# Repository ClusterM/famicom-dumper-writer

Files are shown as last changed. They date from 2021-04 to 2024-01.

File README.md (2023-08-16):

# Famicom/NES Dumper/Writer

## Overview

This is a powerfull dumper/writer for Famicom/NES cartridges and Famicom Disc System cards. The goal of the project is to create an ideal famicom data bus simulator. It's using a very accurate M2 cycle simulation and FSMC (Flexible Static Memory Controller) to access PRG and CHR memory. FSMC is precisely synchronized with the M2 clock signal using a CPLD chip. Also, this device is very fast.





COOLBOY writing using GPIO pins

Video about dumper development (English subtitles):

Video preview (https://youtu.be/j_rteVX5q-g)

You can use it to:

* Dump cartridges, so you can play copy of your cartridge on emulator.
* Dump reset-based cartridges, there is command to simulate reset press.
* Dump cartridges that requires a continuous clock on M2 pin.
* Use it with [very flexible and multiplatform client](https://github.com/ClusterM/famicom-dumper-client), it's using C# scripts.
* Read/write battery backed saves, so that you can continue your saved game on emulator/console and vice-versa.
* (Re)write [COOLGIRL](https://github.com/ClusterM/coolgirl-famicom-multicard) cartridges.
* (Re)write ultracheap chinese [COOLBOY (AA6023 chip based)](https://www.nesdev.org/wiki/NES_2.0_Mapper_268) cartridges (mapper 268). Soldering is required for a cheap cartridges but it's very simple. Some more expensive cartridges can be rewritten without soldering.
* (Re)write UNROM-512 cartridges (RetroUSB, mapper 30).
* Read and write Famicom Disk System cards using FDS drive with the RAM adapter.
* Test your cartridges.
* Do some reverse engineering.
* Anything else that requires Famicom/NES bus simulation.

## Schematic

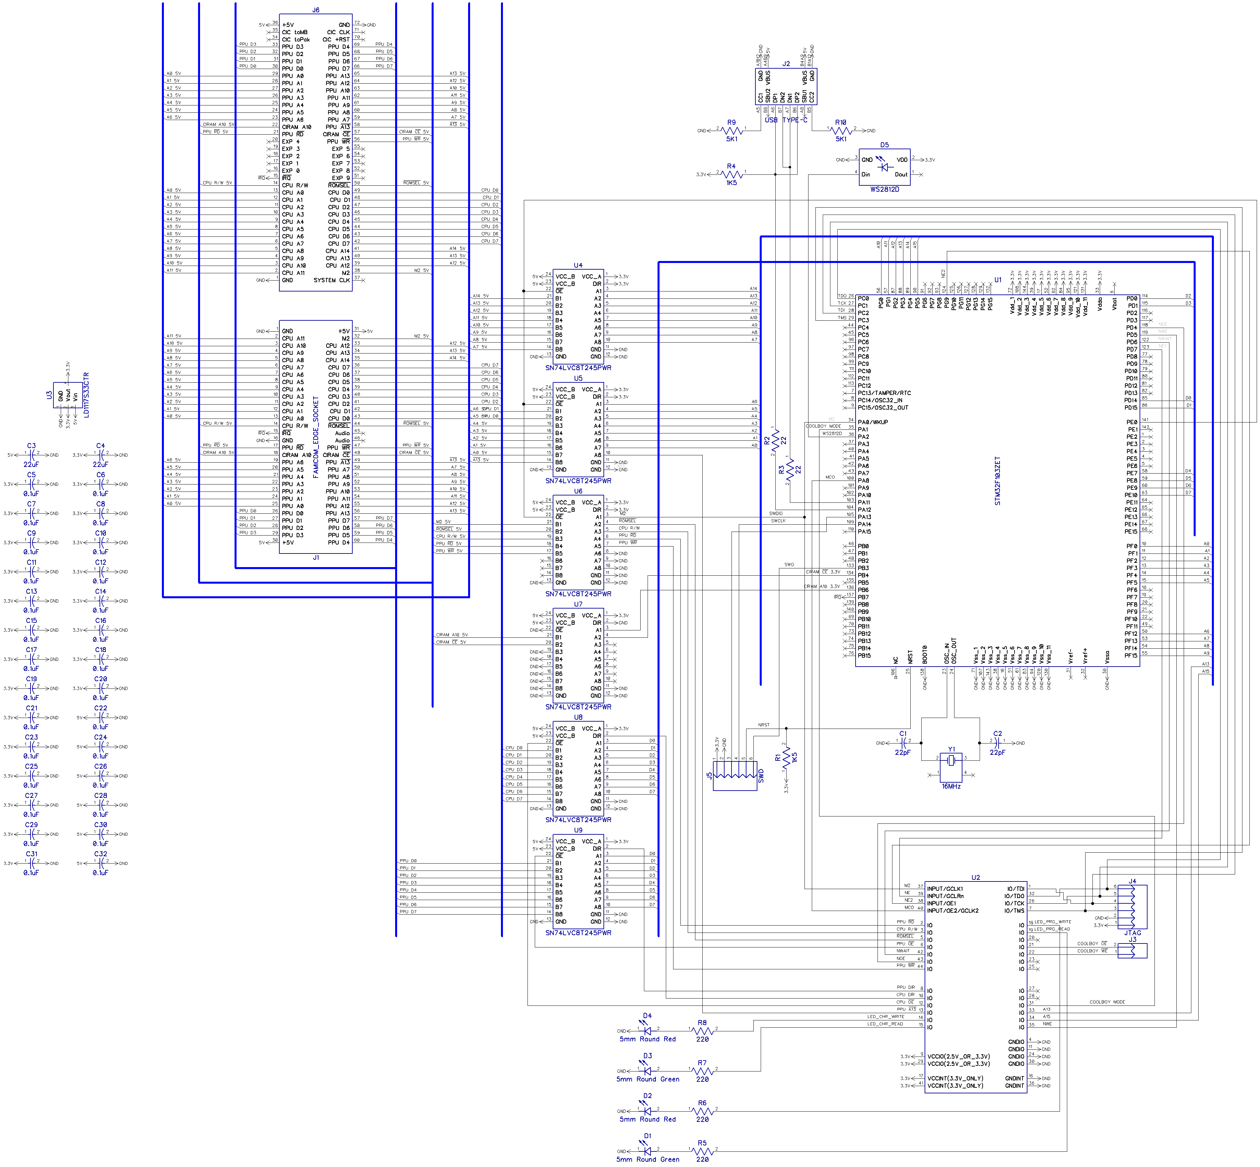
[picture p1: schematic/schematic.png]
Schematic


Bill of Materials:

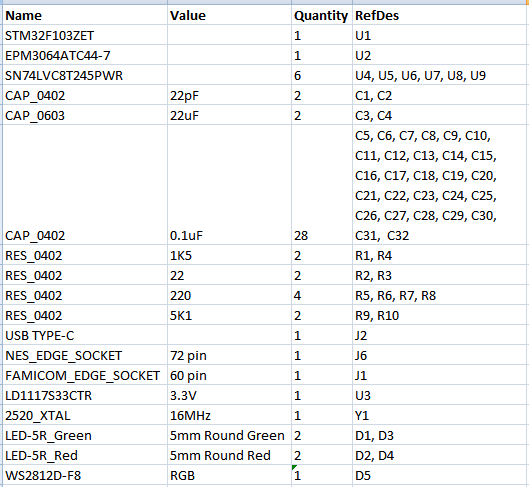
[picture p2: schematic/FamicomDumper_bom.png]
BoM


## Firmware

You need to write firmware to two chips: the STM32F103ZET microcontroller and the EPM3064 CPLD. But actually you need only to flash bootloader to STM32 using ST-Link programmer. Using bootloader you can flash both firmwares: to the STM32F103ZET and to the EPM3064.

How to use bootloader:
* Disconnect device from USB.
* Short the ground and the IRQ pins using tweezers or scissors.

* Connect the device to the USB of your PC/Mac. The RGB LED should turn green. Try again if it's not green.
* Remove tweezers/scissors quickly while the LED is green.
* The LED should turn yellow. Try again if it's not yellow.
* The device should be detected as USB drive.
* Format it to FAT32 if it's not formatted yet. You need to do it only once.
* Write SVF file with the firmware for the EPM3064 chip and BIN file with the firmware for the STM32F103ZET chip to this USB drive. You can write both at the same time.
* The RGB LED should turn white.
* Wait for some time: ~30 seconds for EPM3064 firmware, ~1 second for STM32F103ZET firmware.
* The RGB LED should turn green on success, red on some error.
* Reconnect device to your PC/Mac.

You can update the firmwares using the same way without any additional hardware (only tweezers or scissors :))

## Driver

This device shound work without any additional drivers on all modern operating systems, as virtual serial port.

## Software

[https://github.com/ClusterM/famicom-dumper-client](https://github.com/ClusterM/famicom-dumper-client)

## Donate
PayPal: cluster@cluster.wtf

https://www.donationalerts.com/r/clustermeerkat

https://boosty.to/cluster

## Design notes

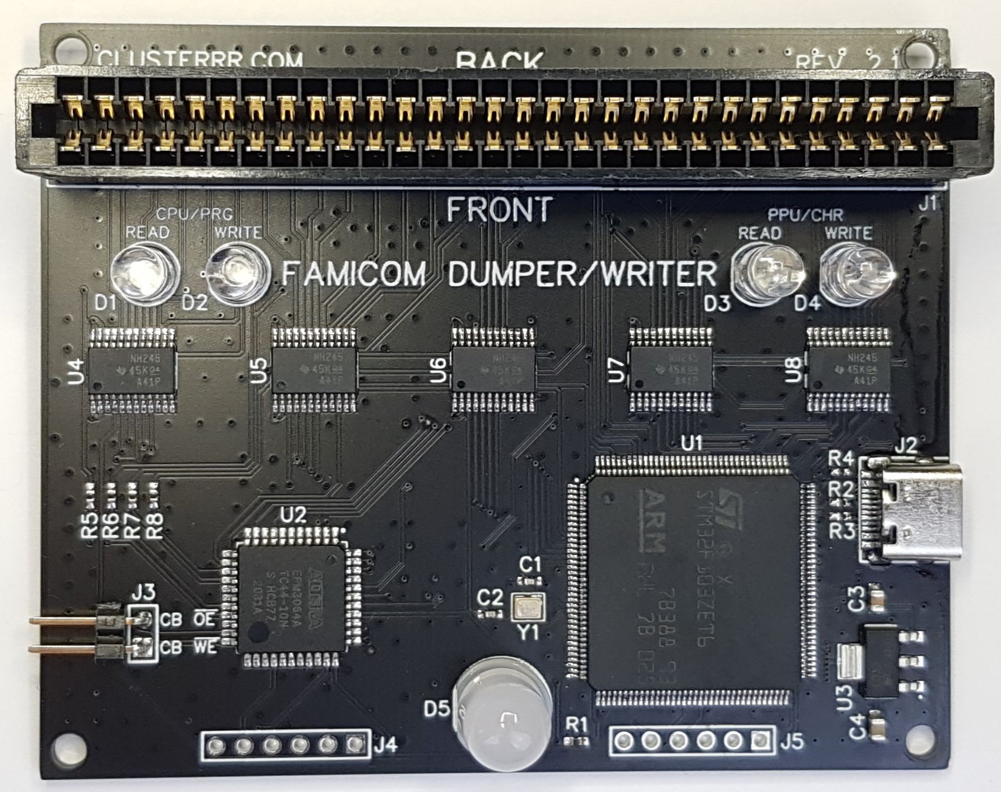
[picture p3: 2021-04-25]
photos/dumper2.jpg

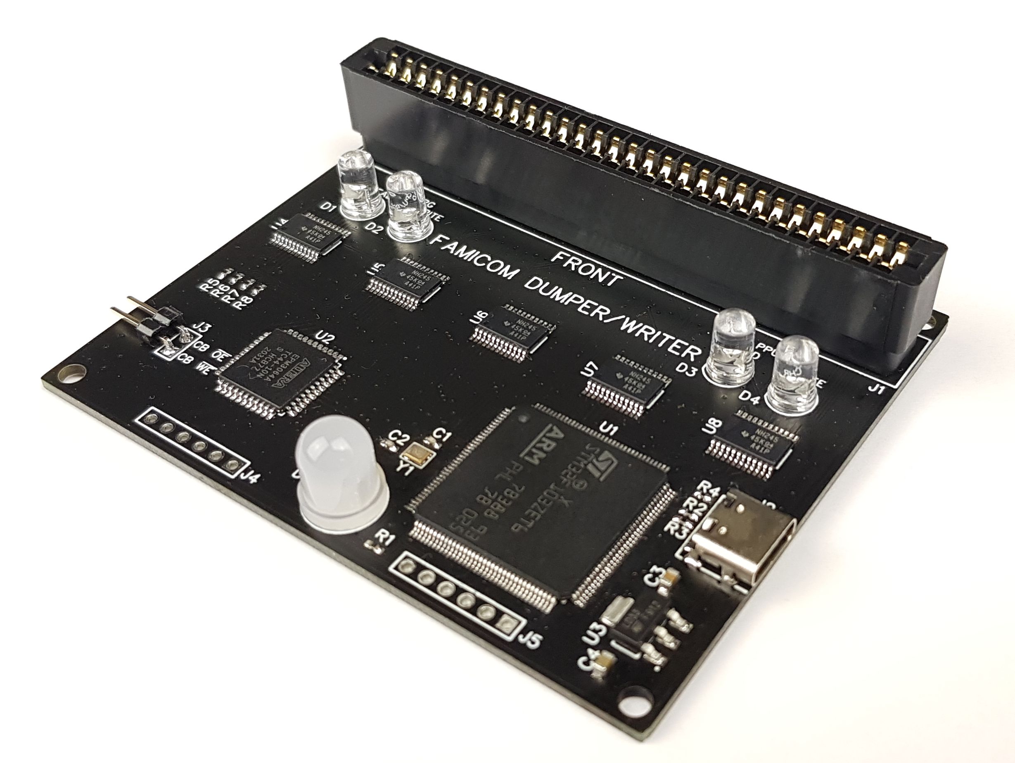
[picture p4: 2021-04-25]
photos/dumper.jpg

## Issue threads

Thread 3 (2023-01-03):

Alternative CPLD?

djbiohazard, 2023-01-03:
The EPM3064 seems to be EOL, is there any other alternative chip that could be used?

ClusterM, 2023-01-19:
Yes, i think. But it's developed for EPM3064 and there is no pin-compatible alternatives :( Need to change schematic and board for  something else.

ClusterM, 2023-01-20:
I think that it's possible to migrate to EPM7064AETC44.

derchr, 2023-10-20:
Hello, is it possible to use EPM3064ATC44-10N instead of EPM3064ATC44-7 as the latter one is hardly available?

ClusterM, 2023-10-22:
> Hello, is it possible to use EPM3064ATC44-10N instead of EPM3064ATC44-7 as the latter one is hardly available?

Hi! Yes, they are compatible as far as i can remember.

derchr, 2023-10-24:
> > Hello, is it possible to use EPM3064ATC44-10N instead of EPM3064ATC44-7 as the latter one is hardly available?
>
> Hi! Yes, they are compatible as far as i can remember.

Thanks!

Closed 2023-08-07.

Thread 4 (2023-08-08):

Configuration of Altera EPM3064 cant' be updated

kolmogorovpavel, 2023-08-08:
After copying file FamicomDumper.svf to drive, led is always become red. After reconnecting drive the file is still there.

Regle-Lin, 2023-08-11:
when I programmed the FamicomDumperBootloader.bin or FamicomDumper.bin to STM32 MCU by STLINK V2 and connect the dumper to USB, the device cannot recognize by PC(win10 64 bit), the PC showing unknow device, if anyone could give a guidance for how to make it work will be appreciated.

kolmogorovpavel, 2023-08-11:
You just need to programm FamicomDumperBootloader.bin to STM32 MCU by STLINK V2. (Power dumper by usb) Then you should short 15 and 16 pin and connect to usb, then remove connection between 15 an 16 (you can see it in the video). The led become green first, then yellow and USB drive will be detected. You should format it before copying FamicomDumper.bin to the drive.

Regle-Lin, 2023-08-12:
My dumper now working perfect! my problem is I'm used the oscillator(need provide vdd for work) not the crystal for STM32, so I need to re-soldering the right pin for let the 16M signal input from STM32 pin23.
in your case, maybe you need to check the ALTERA chip soldering if any shorted pin or mounted in wrong direction(such mistaken happened to me), if confirmed no any hardware issues, please try to update the FW one by one, try only the STM32 BIN first and then CPLD, when the CPLD FW updating, all the read/write LED is dim light and the CHR red LED will be solid light when the CPLD FW update done.

kolmogorovpavel, 2023-08-13:
In my case dumper was bought maybe a year or two ago. So it has an old firmware. A updated bootloader first with stlink, then stm32 firmware by copying to 192kb drive. Dumper is working now, but I can't update CPLD. Maybe old pcb has some differences. But all tryes to copy svf ended up with red light of rgb led.

Regle-Lin, 2023-08-14:
you can try to use the USB-BLASTER for the CPLD programming, but I'm suggest you to check the connection differences to the latest release of PCB layout.

serperus, 2023-10-12:
> In my case dumper was bought maybe a year or two ago. So it has an old firmware. A updated bootloader first with stlink, then stm32 firmware by copying to 192kb drive. Dumper is working now, but I can't update CPLD. Maybe old pcb has some differences. But all tryes to copy svf ended up with red light of rgb led.

Try to copy to sd card both files together. Bin and svf at the same time.

kolmogorovpavel, 2023-10-15:
> Try to copy to ubs flash both files together. Bin and svf at the same time.
That was the first that I've tried. With no luck.

ClusterM, 2024-02-13:
> In my case dumper was bought maybe a year or two ago. So it has an old firmware. A updated bootloader first with stlink, then stm32 firmware by copying to 192kb drive. Dumper is working now, but I can't update CPLD. Maybe old pcb has some differences. But all tryes to copy svf ended up with red light of rgb led.

Hi. Which dumper revision you have? Only rev3.2+ has CPLD programming lines. So you can't update CPLD firmware via bootloader on old PCBs even with the latest bootloader.

kolmogorovpavel, 2024-02-14:
Revision of my PCB is 2.1.
So it is clear now that I should use usb-blaster.

Closed 2024-03-18.

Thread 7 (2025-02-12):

PC can not recogonize the stm32

hualazimo7, 2025-02-12:
when I programmed the FamicomDumperBootloader.bin or FamicomDumper.bin to STM32 MCU by STLINK V2 and connect the dumper to USB, the device cannot be recognized by PC(win10 64 bit), the PC showing unknow device, if anyone could give a guidance for how to make it work will be appreciated.

BTW I used the right 16MHZ crystal.

hualazimo7, 2025-02-12:
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

I didn't change the layout jusy replace some 0402 components by 0603 ones.

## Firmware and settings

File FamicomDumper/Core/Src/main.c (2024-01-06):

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
/* Includes ------------------------------------------------------------------*/
#include "main.h"
#include "usb_device.h"

/* USER CODE BEGIN Includes */
#include <stdio.h>
#include "dumper.h"
#include "comm.h"
#include "flash.h"
#include "unrom512.h"
#include "fds.h"
#include "led.h"
/* USER CODE END Includes */

TIM_HandleTypeDef htim1;
TIM_HandleTypeDef htim2;
TIM_HandleTypeDef htim3;
TIM_HandleTypeDef htim4;
TIM_HandleTypeDef htim5;
DMA_HandleTypeDef hdma_tim5_ch3_up;

SRAM_HandleTypeDef hsram1;
SRAM_HandleTypeDef hsram2;

void SystemClock_Config(void);
static void MX_GPIO_Init(void);
static void MX_DMA_Init(void);
static void MX_FSMC_Init(void);
static void MX_TIM2_Init(void);
static void MX_TIM5_Init(void);
static void MX_TIM1_Init(void);
static void MX_TIM3_Init(void);
static void MX_TIM4_Init(void);
/* USER CODE BEGIN 0 */
int _write(int file, char *ptr, int len)
{
  for (int i = 0; i < len; i++)
    ITM_SendChar((*ptr++));
  return len;
}

/* USER CODE END 0 */

/**
  * @brief  The application entry point.
  * @retval int
  */
int main(void)
{
  /* MCU Configuration--------------------------------------------------------*/

  /* Reset of all peripherals, Initializes the Flash interface and the Systick. */
  HAL_Init();

  /* Configure the system clock */
  SystemClock_Config();

  /* Initialize all configured peripherals */
  MX_GPIO_Init();
  MX_DMA_Init();
  MX_FSMC_Init();
  MX_USB_DEVICE_Init();
  MX_TIM2_Init();
  MX_TIM5_Init();
  MX_TIM1_Init();
  MX_TIM3_Init();
  MX_TIM4_Init();
  /* USER CODE BEGIN 2 */
  // Microsecond counter
  HAL_TIM_Base_Start(&htim1);
  // M2 PWM
  HAL_TIM_PWM_Start(&htim2, TIM_CHANNEL_1);
  // 1000*M2 clock counter (slave of htim2 with /1000 prescaler)
  HAL_TIM_Base_Start(&htim3);
  // M2 clock counter (slave of htim2)
  HAL_TIM_Base_Start(&htim4);
  comm_init();
  printf("Started.\n");
  /* USER CODE END 2 */

  /* Infinite loop */
  /* USER CODE BEGIN WHILE */
  uint16_t address;
  uint32_t address32;
  uint16_t length;
  led_blue();

  while (1)
  {
    led_idle();

    if (comm_recv_done)
    {
      comm_recv_done = 0;
      switch (comm_recv_command)
      {
      case COMMAND_PRG_INIT:
        comm_start(COMMAND_PRG_STARTED, 13);
        comm_send_byte(PROTOCOL_VERSION);
        comm_send_byte(0xFF);
        comm_send_byte(0xFF); // unlimited send buffer
        comm_send_byte((RECV_BUFFER_SIZE - 8) & 0xFF);
        comm_send_byte(((RECV_BUFFER_SIZE - 8) >> 8) & 0xFF);
        comm_send_byte(FIRMWARE_VERSION_MAJOR & 0xFF);
        comm_send_byte((FIRMWARE_VERSION_MAJOR >> 8) & 0xFF);
        comm_send_byte(FIRMWARE_VERSION_MINOR);
        comm_send_byte(FIRMWARE_VERSION_SUFFIX);
#ifndef DEBUG
        comm_send_byte(HARDWARE_VERSION[0]);
        comm_send_byte(HARDWARE_VERSION[1]);
        comm_send_byte(HARDWARE_VERSION[2]);
        comm_send_byte(HARDWARE_VERSION[3]);
#else
        comm_send_byte(0);
        comm_send_byte(0);
        comm_send_byte(0);
        comm_send_byte(0);
#endif
        set_coolboy_gpio_mode(0);
        break;

      case COMMAND_COOLBOY_READ_REQUEST:
      case COMMAND_PRG_READ_REQUEST:
        address = recv_buffer[0] | ((uint16_t) recv_buffer[1] << 8);
        length = recv_buffer[2] | ((uint16_t) recv_buffer[3] << 8);
        read_prg_send(address, length);
        break;

      case COMMAND_PRG_CRC_READ_REQUEST:
        address = recv_buffer[0] | ((uint16_t) recv_buffer[1] << 8);
        length = recv_buffer[2] | ((uint16_t) recv_buffer[3] << 8);
        read_prg_crc_send(address, length);
        break;

      case COMMAND_PRG_WRITE_REQUEST:
        address = recv_buffer[0] | ((uint16_t) recv_buffer[1] << 8);
        length = recv_buffer[2] | ((uint16_t) recv_buffer[3] << 8);
        write_prg(address, length, (uint8_t*) &recv_buffer[4]);
        comm_start(COMMAND_PRG_WRITE_DONE, 0);
        break;

      case COMMAND_RESET:
        reset();
        comm_start(COMMAND_RESET_ACK, 0);
        break;

      case COMMAND_FLASH_ERASE_SECTOR_REQUEST:
      case COMMAND_COOLBOY_ERASE_SECTOR_REQUEST:
        erase_flash_sector();
        break;

      case COMMAND_FLASH_WRITE_REQUEST:
      case COMMAND_COOLBOY_WRITE_REQUEST:
        address = recv_buffer[0] | ((uint16_t) recv_buffer[1] << 8);
        length = recv_buffer[2] | ((uint16_t) recv_buffer[3] << 8);
        write_flash(address, length, (uint8_t*) &recv_buffer[4]);
        break;

      case COMMAND_UNROM512_ERASE_REQUEST:
        erase_unrom512();
        break;

      case COMMAND_UNROM512_WRITE_REQUEST:
        address32 = recv_buffer[0] | ((uint32_t) recv_buffer[1] << 8) | ((uint32_t) recv_buffer[2] << 16) | ((uint32_t) recv_buffer[3] << 24);
        length = recv_buffer[4] | ((uint16_t) recv_buffer[5] << 8);
        write_unrom512(address32, length, (uint8_t*) &recv_buffer[6]);
        break;

      case COMMAND_CHR_INIT:
        comm_start(COMMAND_CHR_STARTED, 0);
        break;

      case COMMAND_CHR_READ_REQUEST:
        address = recv_buffer[0] | ((uint16_t) recv_buffer[1] << 8);
        length = recv_buffer[2] | ((uint16_t) recv_buffer[3] << 8);
        read_chr_send(address, length);
        break;

      case COMMAND_CHR_CRC_READ_REQUEST:
        address = recv_buffer[0] | ((uint16_t) recv_buffer[1] << 8);
        length = recv_buffer[2] | ((uint16_t) recv_buffer[3] << 8);
        read_chr_crc_send(address, length);
        break;

      case COMMAND_CHR_WRITE_REQUEST:
        address = recv_buffer[0] | ((uint16_t) recv_buffer[1] << 8);
        length = recv_buffer[2] | ((uint16_t) recv_buffer[3] << 8);
        write_chr(address, length, (uint8_t*) &recv_buffer[4]);
        comm_start(COMMAND_CHR_WRITE_DONE, 0);
        break;

      case COMMAND_FDS_READ_REQUEST:
        fds_transfer(recv_buffer[0], recv_buffer[1], 0, 0, 0, 0);
        break;

      case COMMAND_FDS_WRITE_REQUEST:
        fds_transfer(0, 0, recv_buffer[0], (uint8_t*) &recv_buffer[1], (uint16_t*) &recv_buffer[1 + recv_buffer[0]], (uint8_t*) &recv_buffer[1 + recv_buffer[0] + recv_buffer[0] * 2]);
        break;

      case COMMAND_MIRRORING_REQUEST:
        get_mirroring();
        break;

      case COMMAND_SET_FLASH_BUFFER_SIZE:
        set_flash_buffer_size(recv_buffer[0] | ((uint16_t) recv_buffer[1] << 8));
        comm_start(COMMAND_SET_VALUE_DONE, 0);
        break;

      case COMMAND_SET_COOLBOY_GPIO_MODE:
        set_coolboy_gpio_mode(recv_buffer[0]);
        comm_start(COMMAND_SET_VALUE_DONE, 0);
        break;
      }
      led_off();
    }
    /* USER CODE END WHILE */

    /* USER CODE BEGIN 3 */
  }
  /* USER CODE END 3 */
}

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


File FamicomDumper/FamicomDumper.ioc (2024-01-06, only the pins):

Mcu.UserName=STM32F103ZETx
PA0-WKUP.GPIO_Label=M2
PA0-WKUP.Signal=S_TIM2_CH1_ETR
PA1.GPIO_Label=COOLBOY_MODE
PA1.Signal=GPIO_Output
PA11.Signal=USB_DM
PA12.Signal=USB_DP
PA13.Signal=SYS_JTMS-SWDIO
PA14.Signal=SYS_JTCK-SWCLK
PA2.GPIO_Label=WS2812
PA2.Signal=S_TIM5_CH3
PA8.Signal=RCC_MCO
PB3.Signal=SYS_JTDO-TRACESWO
PB4.GPIO_Label=CIRAM_CE
PB4.Signal=GPIO_Input
PB6.GPIO_Label=CIRAM_A10
PB6.Signal=GPIO_Input
PB7.GPIO_Label=IRQ
PB7.Signal=GPIO_Input
PC0.GPIO_Label=TDO
PC0.Signal=GPIO_Input
PC1.GPIO_Label=TCK
PC1.Signal=GPIO_Input
PC2.GPIO_Label=TDI
PC2.Signal=GPIO_Input
PC3.GPIO_Label=TMS
PC3.Signal=GPIO_Input
PD0.Signal=FSMC_D2_DA2
PD1.Signal=FSMC_D3_DA3
PD14.Signal=FSMC_D0_DA0
PD15.Signal=FSMC_D1_DA1
PD4.Signal=FSMC_NOE
PD5.Signal=FSMC_NWE
PD6.Signal=FSMC_NWAIT
PD7.Signal=FSMC_NE1
PE0.GPIO_Label=SHIFTERS_OE
PE0.Signal=GPIO_Output
PE10.Signal=FSMC_D7_DA7
PE7.Signal=FSMC_D4_DA4
PE8.Signal=FSMC_D5_DA5
PE9.Signal=FSMC_D6_DA6
PF0.Signal=FSMC_A0
PF1.Signal=FSMC_A1
PF12.Signal=FSMC_A6
PF13.Signal=FSMC_A7
PF14.Signal=FSMC_A8
PF15.Signal=FSMC_A9
PF2.Signal=FSMC_A2
PF3.Signal=FSMC_A3
PF4.Signal=FSMC_A4
PF5.Signal=FSMC_A5
PG0.Signal=FSMC_A10
PG1.Signal=FSMC_A11
PG2.Signal=FSMC_A12
PG3.Signal=FSMC_A13
PG4.Signal=FSMC_A14
PG5.Signal=FSMC_A15
PG9.Signal=FSMC_NE2

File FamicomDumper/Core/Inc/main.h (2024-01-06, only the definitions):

#define TDO_Pin GPIO_PIN_0
#define TDO_GPIO_Port GPIOC
#define TCK_Pin GPIO_PIN_1
#define TCK_GPIO_Port GPIOC
#define TDI_Pin GPIO_PIN_2
#define TDI_GPIO_Port GPIOC
#define TMS_Pin GPIO_PIN_3
#define TMS_GPIO_Port GPIOC
#define M2_Pin GPIO_PIN_0
#define M2_GPIO_Port GPIOA
#define COOLBOY_MODE_Pin GPIO_PIN_1
#define COOLBOY_MODE_GPIO_Port GPIOA
#define WS2812_Pin GPIO_PIN_2
#define WS2812_GPIO_Port GPIOA
#define CIRAM_CE_Pin GPIO_PIN_4
#define CIRAM_CE_GPIO_Port GPIOB
#define CIRAM_A10_Pin GPIO_PIN_6
#define CIRAM_A10_GPIO_Port GPIOB
#define IRQ_Pin GPIO_PIN_7
#define IRQ_GPIO_Port GPIOB
#define SHIFTERS_OE_Pin GPIO_PIN_0
#define SHIFTERS_OE_GPIO_Port GPIOE

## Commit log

2020-11-30 COOLBOY pin -> reserved pin
2020-11-30 Increased reset delay to 500ms
    [dumper.c, main.h]
2020-12-01 New VID/PID from pidcodes.github.com
2020-12-01 Added schematic and BoM
    [1 - Top.gbr, 2 - Bottom.gbr, BoardOutline.gbr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]
2020-12-01 Resized bom.png
2020-12-01 Led tuning
2020-12-02 FDS battery check
2020-12-04 White led on reset
    [dumper.c, led.c]
2020-12-04 Minor led fixes, mem2mem DMA removed
    [FamicomDumper.ioc, led.c, main.c]
2020-12-10 Using USB Type-C and EPM3064ATC44 now
    [1 - Top.gbr, 2 - Bottom.gbr, BottomMask.gbr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]
2020-12-13 Tweak to set max USB current to 500ma
2020-12-19 256-byte multibyte program fix
    [dumper.c]
2021-01-05 Fixed invalid USB Type-C pinout
    [1 - Top.gbr, 2 - Bottom.gbr, BottomMask.gbr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]
2021-01-28 USB Type-C fix
    [1 - Top.gbr, 2 - Bottom.gbr, BottomMask.gbr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]
2021-01-28 Mounting holes, J3 reduced to 2 pins, minor changes
    [1 - Top.gbr, 2 - Bottom.gbr, BoardOutline.gbr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]
2021-04-27 Enable pull-up before FDS battery test
2021-04-29 Abort long operations on USB transfer fail
    [comm.h, dumper.c, main.c]
2021-07-13 Added coolboy mode pin, again
2021-07-15 Added 72-pin connector
2021-07-15 Updated RefDes, more capacitors
2021-07-18 Switched to 4 layers
2021-07-18 Moved capacitors to top
2021-07-20 Near complete
    [1 - Top.gbr, 2 - Inner 1.gbr, 3 - Inner 2.gbr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]
2021-07-24 More correct LED timings
    [FamicomDumper.ioc, led.c, main.c]
2021-08-29 Updated schematic.png
2022-10-31 New board, new bootloader
2022-10-31 schematic.png, bom.png
2022-10-31 Schematic updated a bit
2022-10-31 New gerbers
    [1 - Top.gbr, 2 - Bottom.gbr, 2 - Inner 1.gbr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]
2022-11-01 Pull down resistors on USB-C CC lines
    [1 - Top.gbr, 2 - Bottom.gbr, Through.drl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]
2022-11-02 New board version tag
2023-01-18 FDS error handling and refactoring
    [fds.c]
2023-01-19 Critical flash writing fixes
    [flash.c]
2023-01-19 FDS fixes (still not working)
    [fds.c]
2023-01-21 FDS fixes (working now)
    [fds.c]

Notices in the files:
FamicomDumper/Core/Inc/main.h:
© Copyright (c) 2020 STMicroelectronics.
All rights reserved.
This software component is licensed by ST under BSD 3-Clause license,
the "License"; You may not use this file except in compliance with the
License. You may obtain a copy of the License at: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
